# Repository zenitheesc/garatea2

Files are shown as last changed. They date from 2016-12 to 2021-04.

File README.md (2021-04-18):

<h1 align="center" style="color:white; background-color:black">Garatéa 2</h1>
<h4 align="center">Our aerospace probes are attached to balloons filled with helium, carrying astrobiological experiments to the stratosphere, which is crucial so we can have a better understanding about how organisms can survive in space.</h4>

<p align="center">
	<a href="http://zenith.eesc.usp.br/">
    
    </a>
    <a href="https://eesc.usp.br/">
    
    </a>
    <a href="https://github.com/zenitheesc/garatea2/blob/main/LICENSE">
    
    </a>
    <a href="https://github.com/zenitheesc/garatea2/issues">
    
    </a>
    <a href="https://github.com/zenitheesc/garatea2/commits/main">
    
    </a>
    <a href="https://github.com/zenitheesc/garatea2/graphs/contributors">
    
    </a>
    <a href="https://github.com/zenitheesc/garatea2/commits/main">
    
    </a>
    <a href="https://github.com/zenitheesc/garatea2/issues">
    
    </a>
    <a href="https://github.com/zenitheesc/garatea2/pulls">
    
    </a>
</p>

<p align="center">
    <a href="#what-are-aerospace-probes">What are aerospace probes?</a> •
    <a href="#project">Project</a> •
    <a href="#details">Details</a> 
</p>

## What are aerospace probes?

 Our aerospace probes are balloons filled with helium, carrying astrobiological experiments to the stratosphere, which is crucial so we can have a better understanding about how organisms can survive in space.

Although they are part of a greater scientific experiment, the probes themselves are also fascinating from the point of view of embedded systems development. Our probes are equiped with microcontrolers, radios, sensors and cameras; every mission we aim to improve our systems so we can make the next mission even more efficient.

And, to sustain all our experiments and systems, we build reliable and reusable structures, that let us go to space multiple times. 

## Project

After Garatéa-1, our primary goal was to increase the quality of our Space Probes. The Embedded System Architecture was based on an Atmega. In software, we decide to pure C without the use of the Arduino functions, but we also permit the use of C++ during development. We also use Arduino Watchdog Timer. 

In our previous Space Probe, the sensors reads were not constant, because we didn't have solar panels. Now that we do, energy-saving was no longer an issue for us. So, we were able to make many reads. That was also our first try to use GitHub for code versioning. 

The structure was made with Kapton, Aeronautic Depron, 3D printing and Glass Fiber. 

## Details
| Launch Date |Max Altitude|Experiments|
|--|--|--|
| 19/12/2016 | 25,5 km |Bacteria Resistance testing & Biomolecules degradation pattern analysis|

| | | |
|:---:|:---:|:---:|
| |  ||
|  |  | |

---

<p align="center">
    <a href="http://zenith.eesc.usp.br">
    
    </a> 
    <a href="https://www.facebook.com/zenitheesc">
    
    </a> 
    <a href="https://www.instagram.com/zenith_eesc/">
    
    </a>

</p>
<p align = "center">
<a href="zenith.eesc@gmail.com">zenith.eesc@gmail.com</a>
</p>

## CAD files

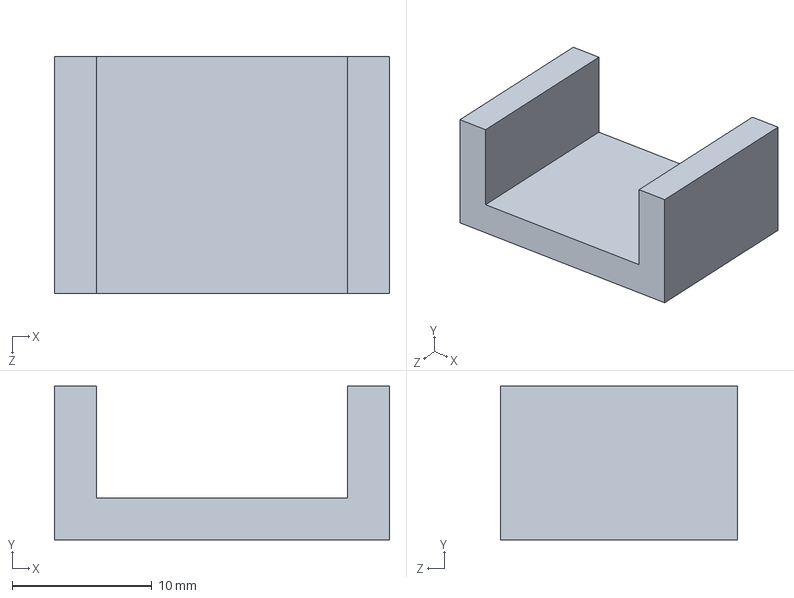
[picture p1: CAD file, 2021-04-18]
Structure/GPS Support.SLDPRT
24.0 x 11.0 x 17.0 mm

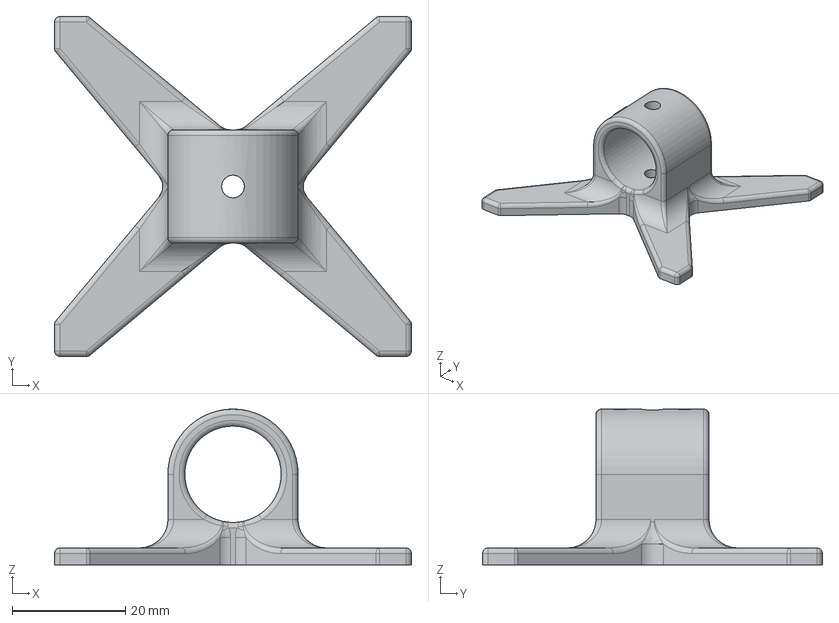
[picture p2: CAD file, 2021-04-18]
Structure/Solar Panel Support.stp
63.0 x 60.0 x 27.5 mm

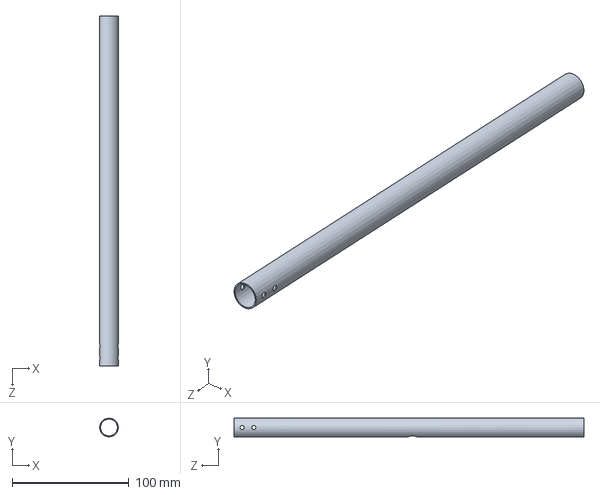
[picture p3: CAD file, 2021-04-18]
Structure/Tube.SLDPRT
16.0 x 16.0 x 300.0 mm

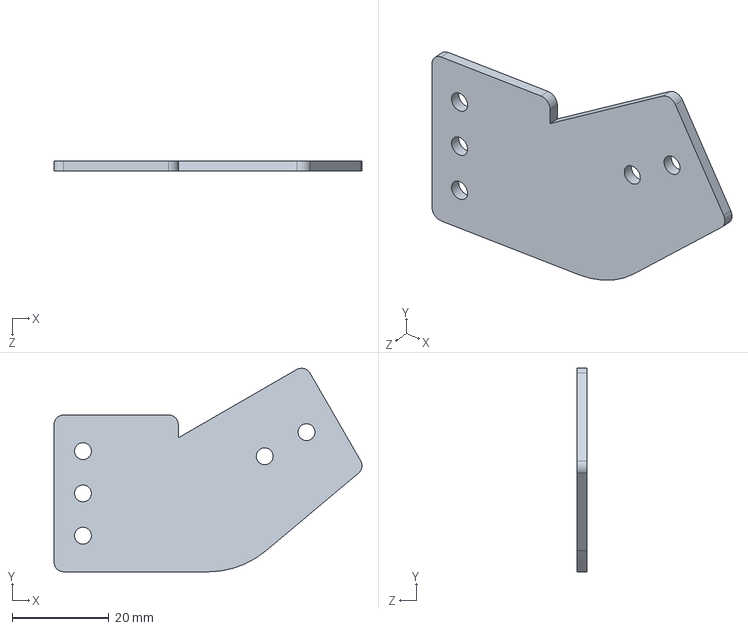
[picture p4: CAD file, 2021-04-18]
Structure/Elbow Board.SLDPRT
63.8 x 42.2 x 2.00 mm

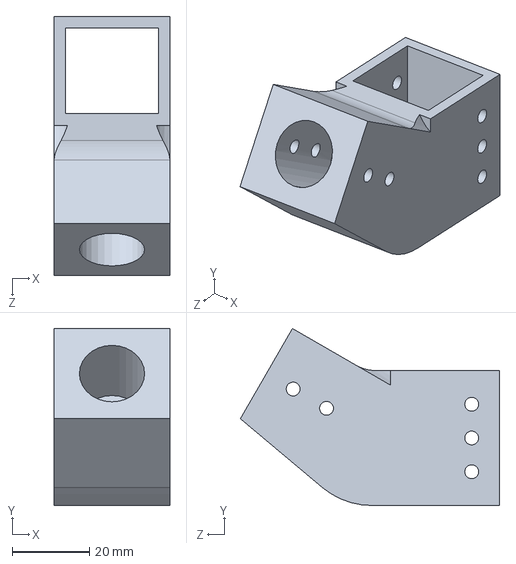
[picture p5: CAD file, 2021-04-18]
Structure/Final Elbow.SLDPRT
30.0 x 45.9 x 67.2 mm

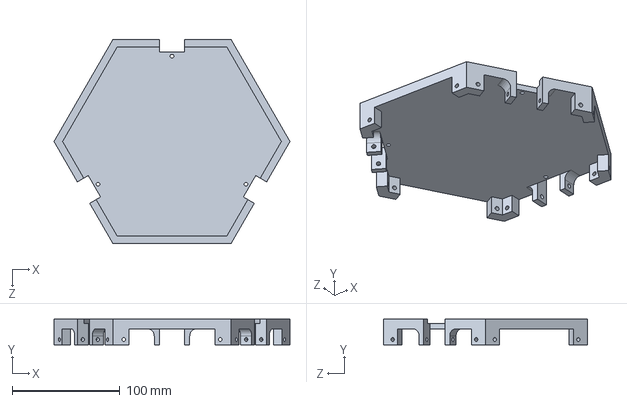
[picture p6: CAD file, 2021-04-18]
Structure/Lower Cover.SLDPRT
219.4 x 24.0 x 190.0 mm

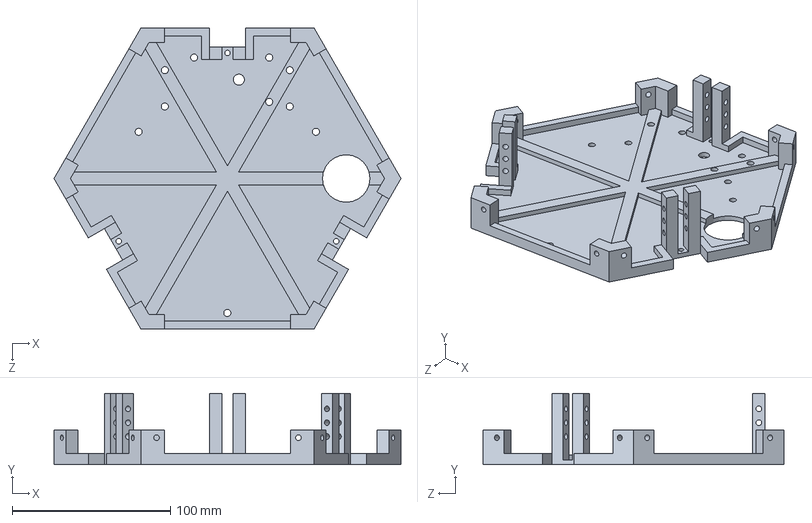
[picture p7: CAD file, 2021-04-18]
Structure/Higher Cover.SLDPRT
219.4 x 45.0 x 190.0 mm

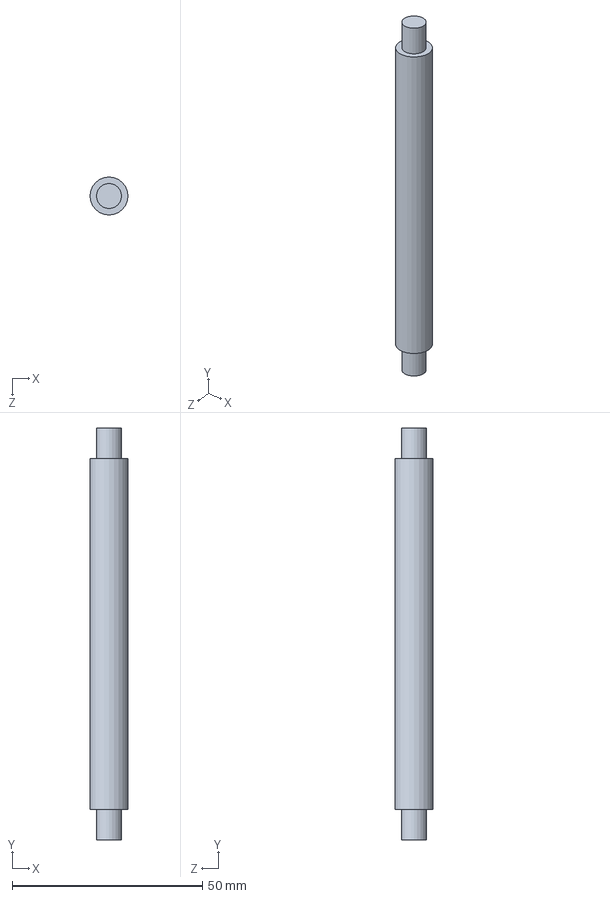
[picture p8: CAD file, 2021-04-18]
Structure/Geiger Counter.SLDPRT
10.0 x 108.4 x 10.0 mm

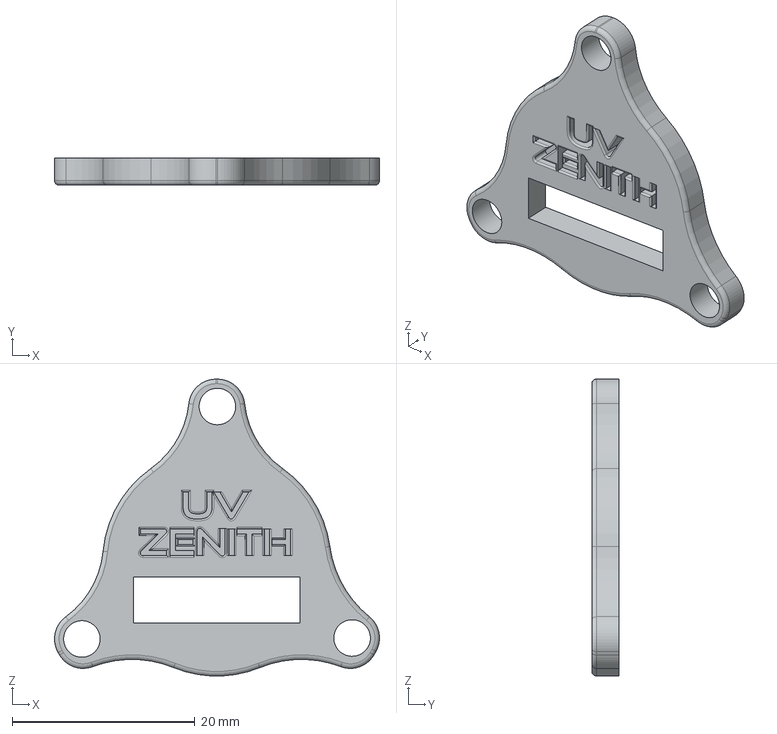
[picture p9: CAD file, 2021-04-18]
Structure/UV Cover.stp
35.6 x 3.00 x 32.5 mm

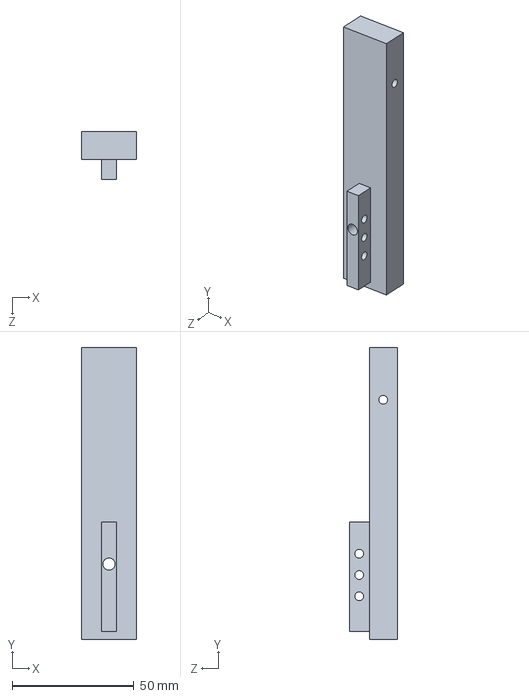
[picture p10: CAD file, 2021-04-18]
Structure/Collum.SLDPRT
22.5 x 120.0 x 19.8 mm

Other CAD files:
Structure/Solar Panel Support.SLDPRT

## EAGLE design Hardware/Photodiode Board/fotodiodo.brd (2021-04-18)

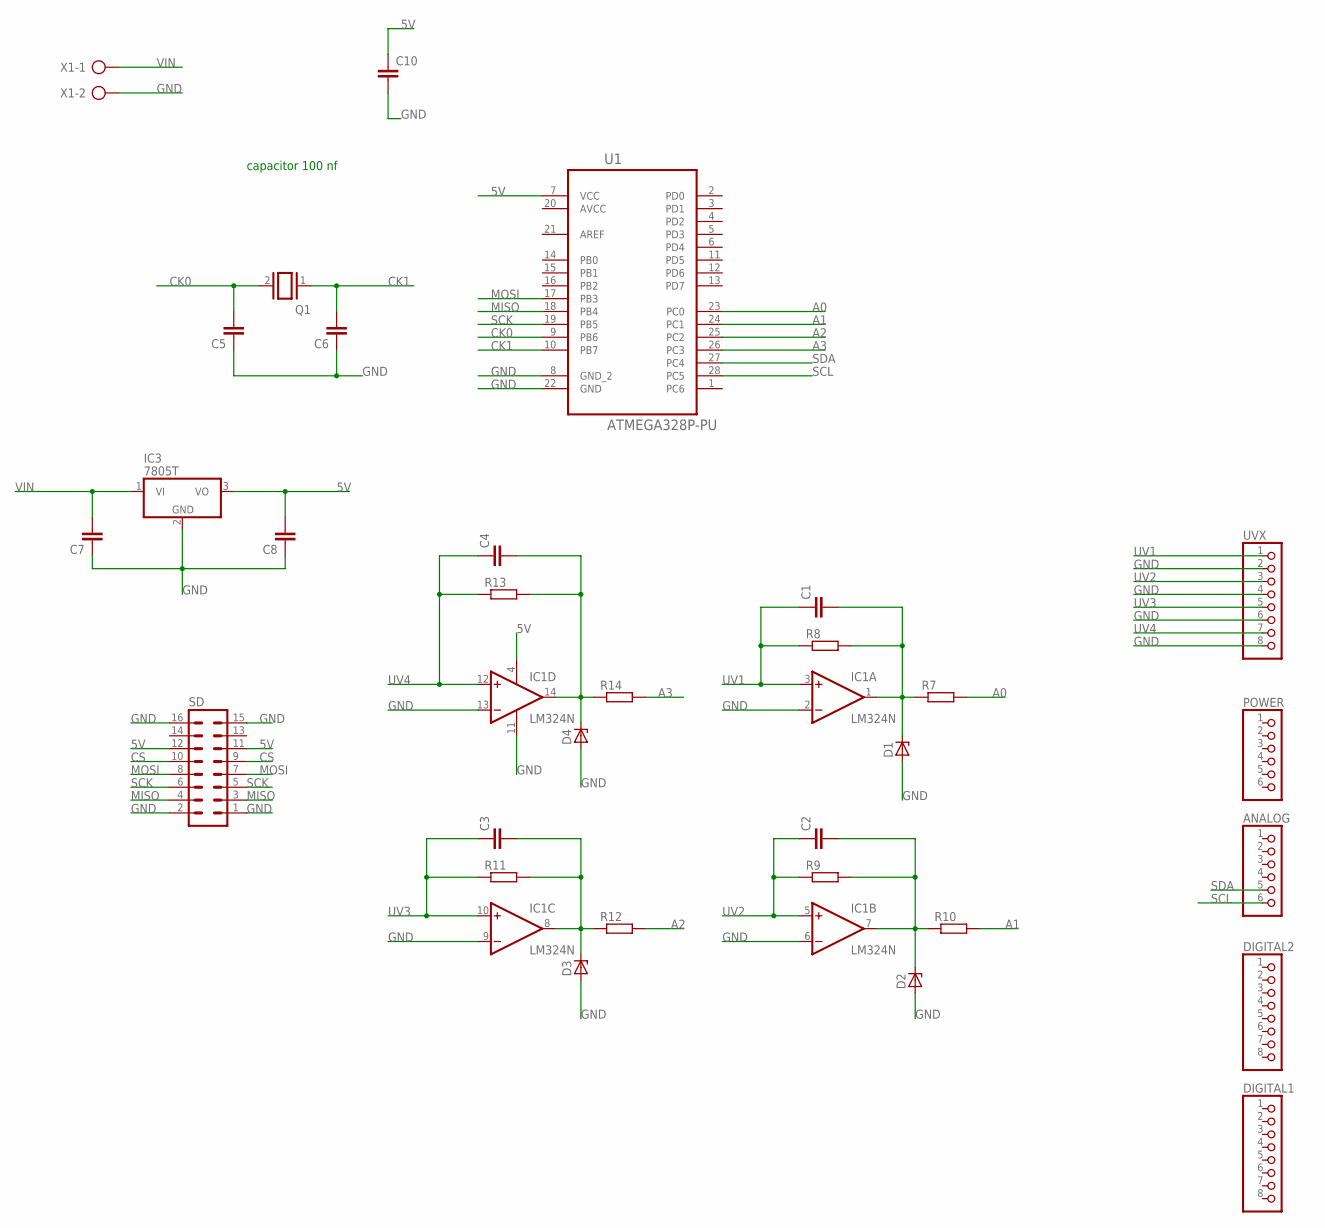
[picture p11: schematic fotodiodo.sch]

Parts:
ANALOG: PINHD-1X6; 1X06
C1, C2, C3, C4, C5, C6, C7, C8: C-EU025-025X050; C025-025X050
C10: C-EU050-055X075; C050-055X075
D1, D2, D3, D4: ZENER-DIODEC1702-15; C1702-15
DIGITAL1, DIGITAL2: PINHD-1X8; 1X08
IC1: LM324N; DIL14
IC3: 7805T; TO220H
POWER: PINHD-1X6; 1X06
Q1: XTAL/S; QS
R7, R8, R9, R10, R11, R12, R13, R14: R-EU_0207/10; 0207/10
SD: MA08-2
U1: ATMEGA328P-PU; DIP254P762X457-28
UVX: PINHD-1X8; 1X08
X1: AK500/2-H

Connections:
5V: C8.2, C10.1, IC1.4 (V+), IC3.3 (VO), SD.11, SD.12, U1.7 (VCC)
A0: R7.2, U1.23 (PC0)
A1: R10.2, U1.24 (PC1)
A2: R12.2, U1.25 (PC2)
A3: R14.2, U1.26 (PC3)
AVCC: U1.20 (AVCC)
CK0: C5.2, Q1.2, U1.9 (PB6)
CK1: C6.2, Q1.1, U1.10 (PB7)
CS: SD.9, SD.10
GND: C5.1, C6.1, C7.1, C8.1, C10.2, D1.A, D2.A, D3.A, D4.A, IC1.2 (-IN), IC1.6 (-IN), IC1.9 (-IN), IC1.11 (V-), IC1.13 (-IN), IC3.2 (GND), SD.1, SD.2, SD.15, SD.16, U1.8 (GND_2), U1.22 (GND), UVX.2, UVX.4, UVX.6, UVX.8, X1.2
MISO: SD.3, SD.4, U1.18 (PB4)
MOSI: SD.7, SD.8, U1.17 (PB3)
unnamed: C1.2, D1.C, IC1.1 (OUT), R7.1, R8.2
unnamed: C4.2, D4.C, IC1.14 (OUT), R13.2, R14.1
unnamed: C3.2, D3.C, IC1.8 (OUT), R11.2, R12.1
unnamed: C2.2, D2.C, IC1.7 (OUT), R9.2, R10.1
SCK: SD.5, SD.6, U1.19 (PB5)
SCL: ANALOG.6, U1.28 (PC5)
SDA: ANALOG.5, U1.27 (PC4)
UV1: C1.1, IC1.3 (+IN), R8.1, UVX.1
UV2: C2.1, IC1.5 (+IN), R9.1, UVX.3
UV3: C3.1, IC1.10 (+IN), R11.1, UVX.5
UV4: C4.1, IC1.12 (+IN), R13.1, UVX.7
VIN: C7.2, IC3.1 (VI), X1.1

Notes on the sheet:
capacitor 100 nf

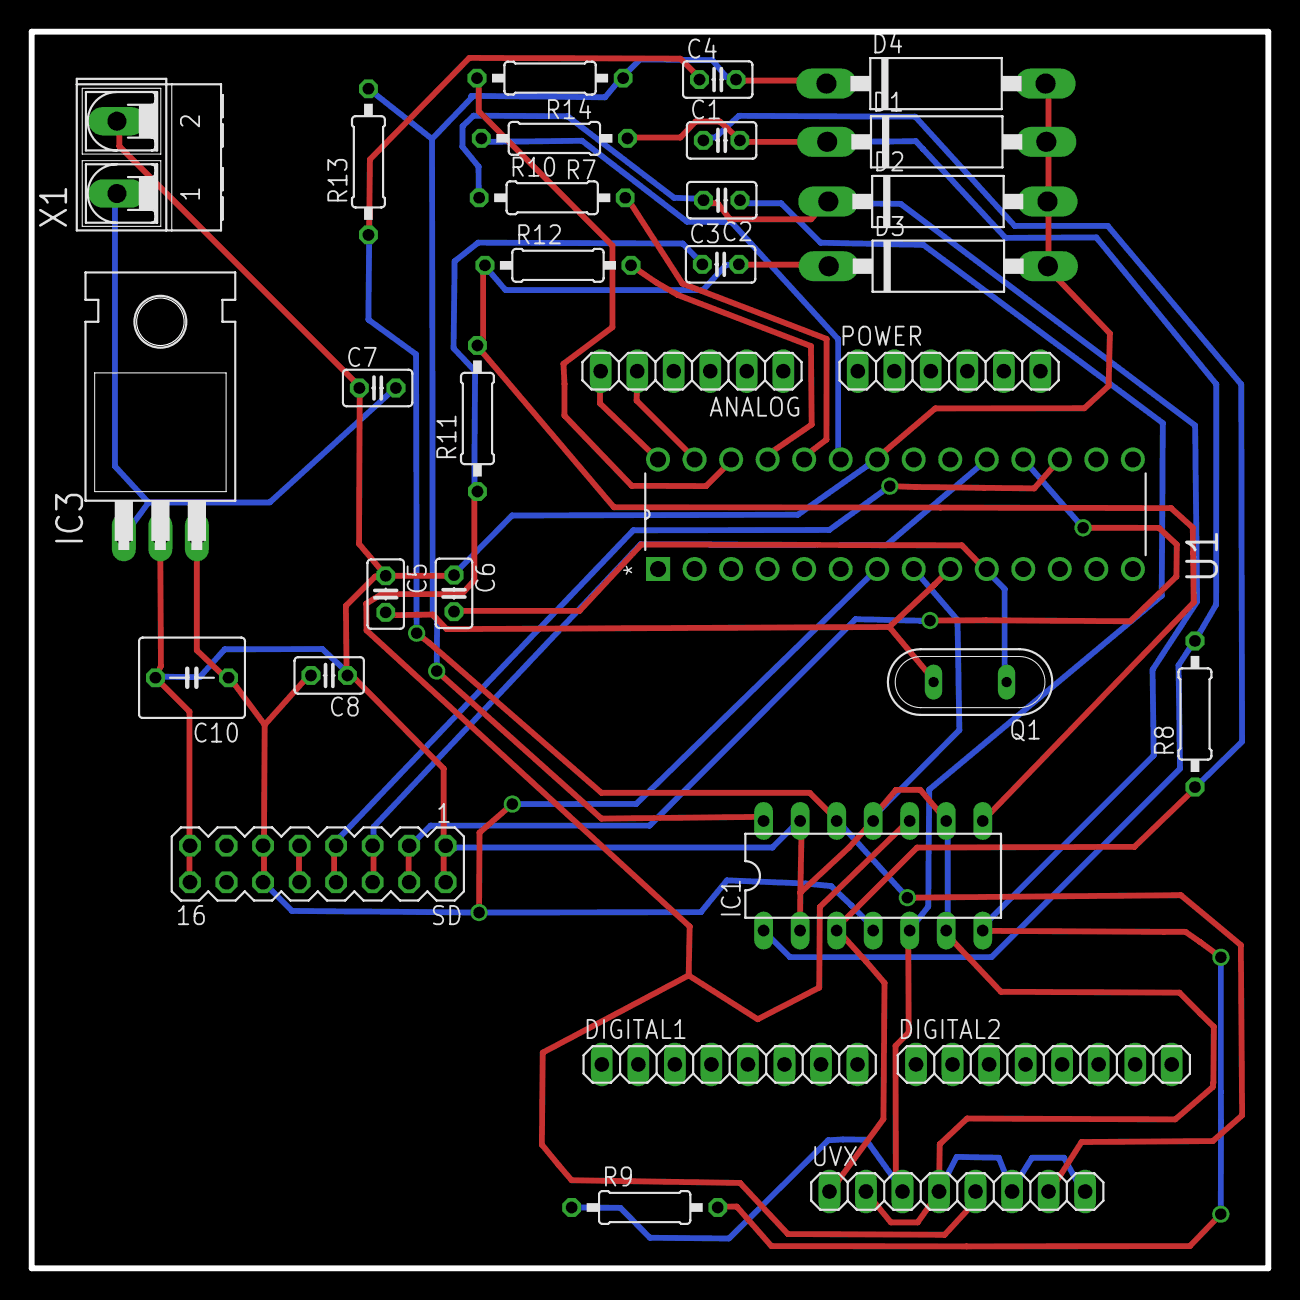
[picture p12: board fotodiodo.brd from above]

Board: 2 copper layers, 86.0 x 86.0 mm, 32 parts (0 on the bottom side), 23 nets.

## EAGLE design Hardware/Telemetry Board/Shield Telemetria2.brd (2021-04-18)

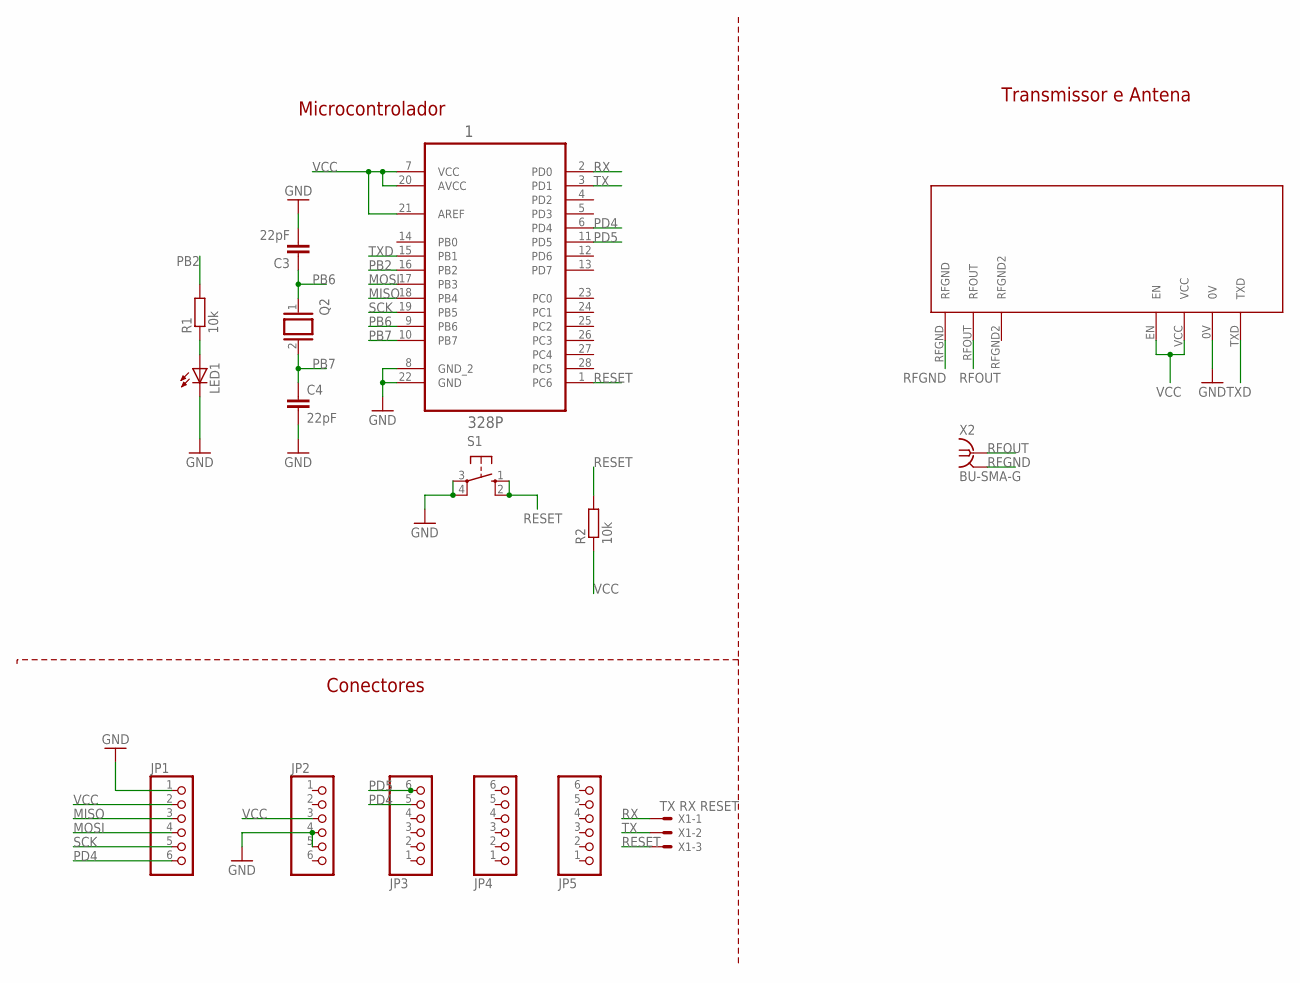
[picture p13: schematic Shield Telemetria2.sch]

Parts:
1: 328P; DIP254P762X457-28
C3, C4: 22pF; C5B4.5
JP1, JP2, JP3, JP4, JP5: PINHD-1X6; 1X06
LED1: LED3MM
Q2: XTAL/S; QS
R1, R2: 10k; 0207/10
S1: 10-XX; B3F-10XX
U$1: NTX2
X1: TX RX RESET; 22-23-2031
X2: BU-SMA-G

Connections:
GND: 1.8 (GND_2), 1.22 (GND), C3.2, C4.2, JP1.1, JP2.4, JP2.5, LED1.K (C), S1.3, S1.4 (P1), U$1.0V
MISO: 1.18 (PB4), JP1.3
MOSI: 1.17 (PB3), JP1.4
unnamed: LED1.A, R1.1
PB2: 1.16 (PB2), R1.2
PB6: 1.9 (PB6), C3.1, Q2.1
PB7: 1.10 (PB7), C4.1, Q2.2
PD4: 1.6 (PD4), JP1.6, JP3.5
PD5: 1.11 (PD5), JP3.6
RESET: 1.1 (PC6), R2.2, S1.1 (S), S1.2 (S1), X1.3
RFGND: U$1.RFGND, X2.2, X2.3 (2), X2.4 (2), X2.5 (2)
RFOUT: U$1.RFOUT, X2.1
RX: 1.2 (PD0), X1.1
SCK: 1.19 (PB5), JP1.5
TX: 1.3 (PD1), X1.2
TXD: 1.15 (PB1), U$1.TXD
VCC: 1.7 (VCC), 1.20 (AVCC), 1.21 (AREF), JP1.2, JP2.3, R2.1, U$1.EN, U$1.VCC

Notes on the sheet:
Conectores
Microcontrolador
Transmissor e Antena

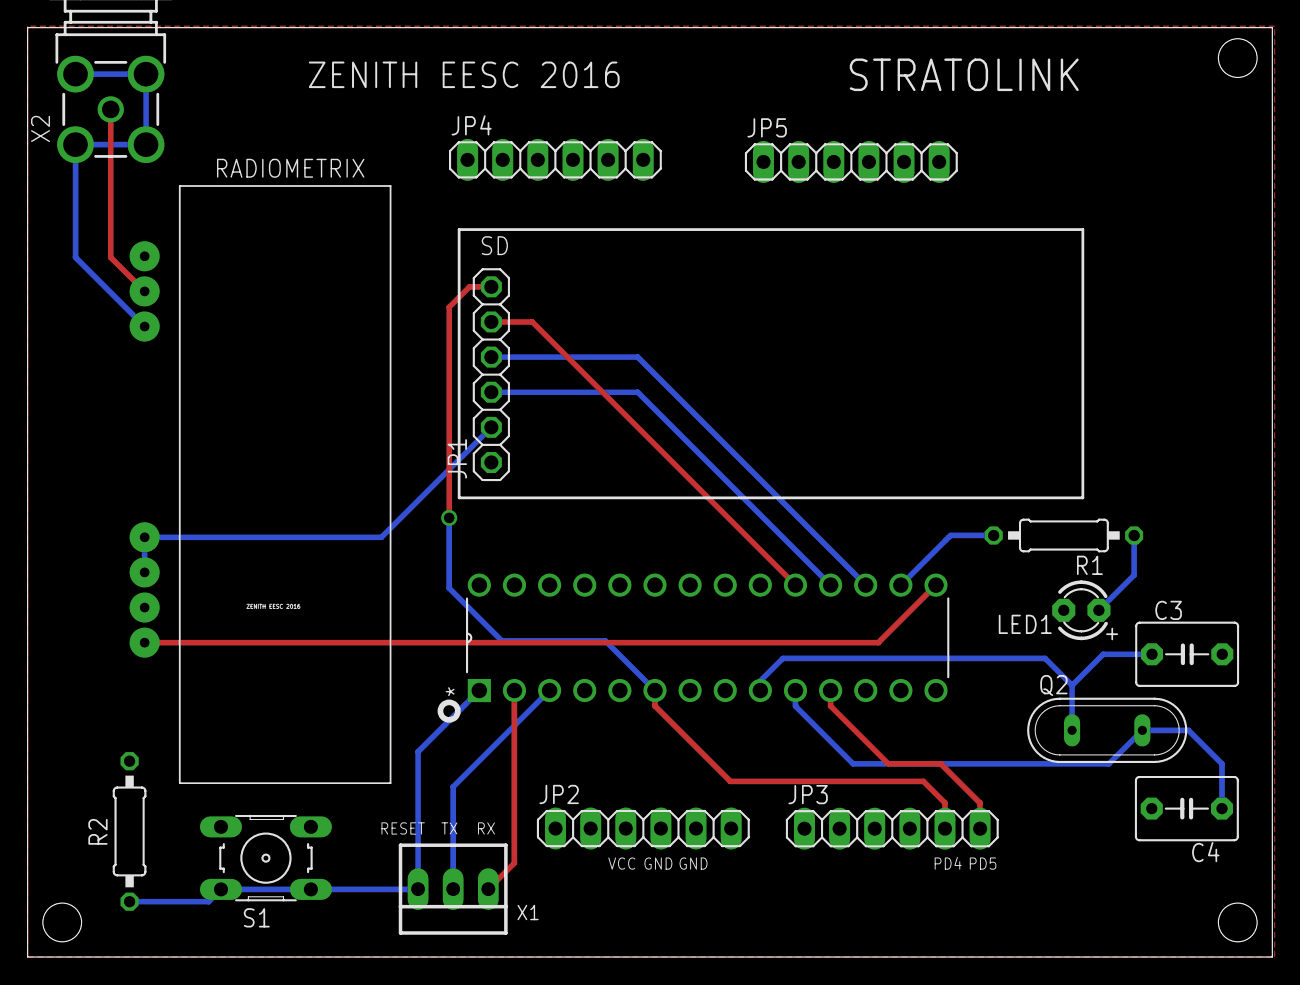
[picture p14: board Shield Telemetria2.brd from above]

Board: 2 copper layers, 90.0 x 67.2 mm, 16 parts (0 on the bottom side), 17 nets.

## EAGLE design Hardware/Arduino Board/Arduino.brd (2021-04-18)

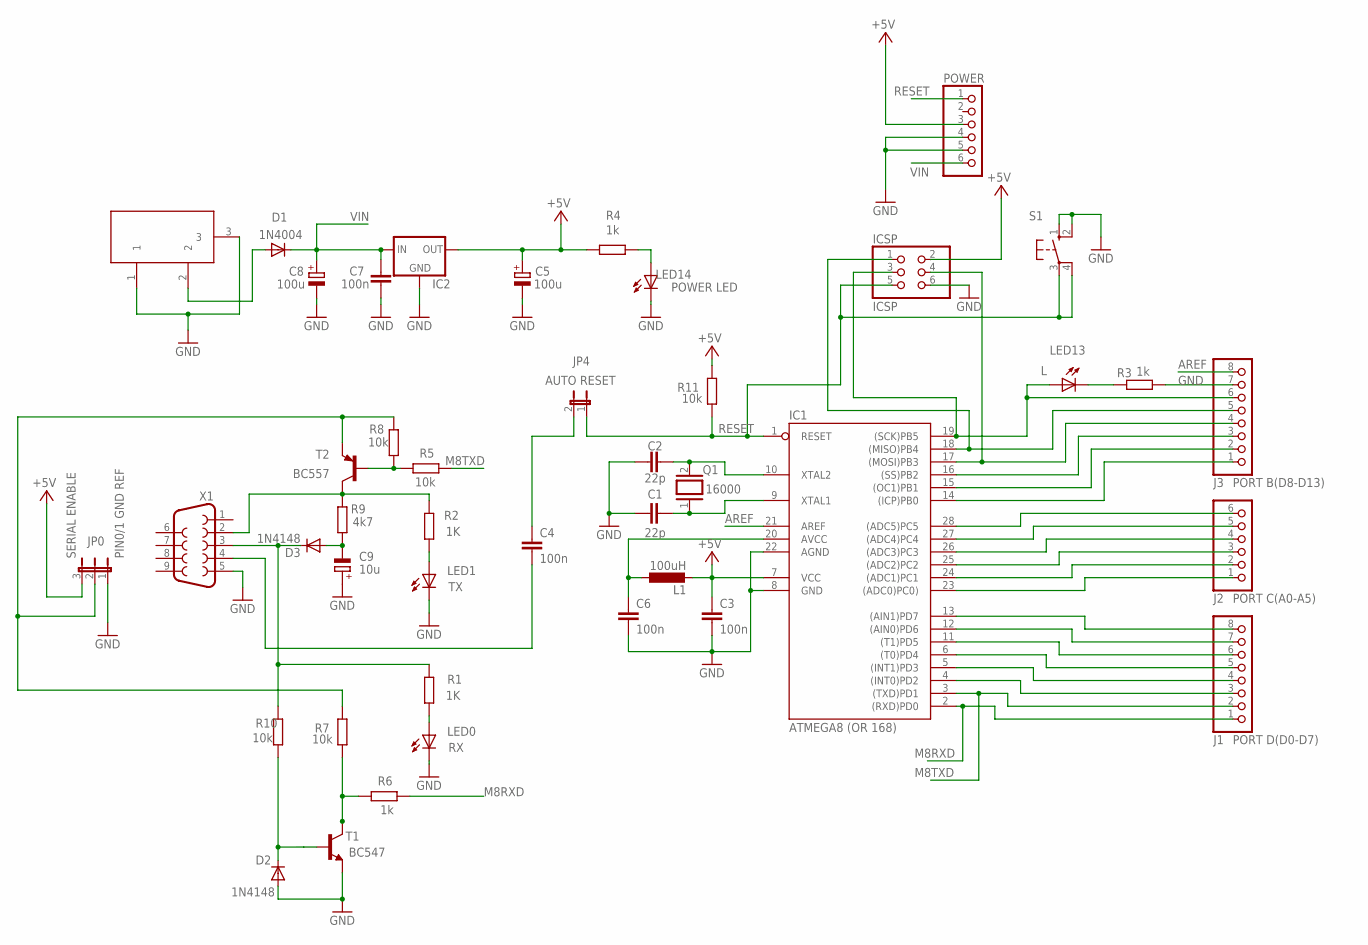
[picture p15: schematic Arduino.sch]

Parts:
C1, C2: 22p; C050-025X075
C3, C4, C6, C7: 100n; C050-025X075
C5, C8: 100u; E3,5-8
C9: 10u; E5-6
D1: 1N4004; DO41-10
D2, D3: 1N4148; DO35-10
DC1: DC21MMX; DC-21MM
IC1: ATMEGA8 (OR 168); DIL28-3
IC2: 78XXL
ICSP: ICSP; 2X03
J1: PORT D(D0-D7); 1X08
J2: PORT C(A0-A5); 1X06
J3: PORT B(D8-D13); 1X08
JP0: JP2W
JP4: AUTO RESET; JP1W
L1: 100uH; 0207/10
LED0: RX; LED3MM
LED1: TX; LED3MM
LED13: L; LED3MM
LED14: POWER LED; LED3MM
POWER: PINHD-1X6; 1X06
Q1: 16000; Q
R1, R2: 1K; 0207/10
R3, R4, R6: 1k; 0207/10
R5, R7, R8, R10, R11: 10k; 0207/10
R9: 4k7; 0207/10
S1: 10-XX; B3F-10XX
T1: BC547; TO92
T2: BC557; TO92-EBC
X1: F09H

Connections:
+5V: C3.1, C5.+, IC1.7 (VCC), IC2.OUT, ICSP.2, JP0.3, L1.2, POWER.3, R4.2, R11.2
AREF: IC1.21 (AREF), J3.8
GND: C1.1, C2.1, C3.2, C5.-, C6.2, C7.1, C8.-, C9.+, D2.A, DC1.1, DC1.3, IC1.8 (GND), IC1.22 (AGND), IC2.GND, ICSP.6, J3.7, JP0.1, LED0.K (C), LED1.K (C), LED14.K (C), POWER.4, POWER.5, R3.1, S1.1 (S), S1.2 (S1), T1.1 (E), X1.5
M8RXD: IC1.2 ((RXD)PD0), J1.1, R6.1
M8TXD: IC1.3 ((TXD)PD1), J1.2, R5.1
unnamed: IC1.18 ((MISO)PB4), ICSP.1, J3.5
unnamed: C9.-, D3.A, R9.1
unnamed: LED14.A, R4.1
unnamed: IC1.17 ((MOSI)PB3), ICSP.4, J3.4
unnamed: IC1.14 ((ICP)PB0), J3.1
unnamed: C1.2, IC1.9 (XTAL1), Q1.1
unnamed: C2.2, IC1.10 (XTAL2), Q1.2
unnamed: D1.A, DC1.2
unnamed: IC1.4 ((INT0)PD2), J1.3
unnamed: IC1.5 ((INT1)PD3), J1.4
unnamed: IC1.6 ((T0)PD4), J1.5
unnamed: IC1.11 ((T1)PD5), J1.6
unnamed: IC1.12 ((AIN0)PD6), J1.7
unnamed: IC1.13 ((AIN1)PD7), J1.8
unnamed: IC1.23 ((ADC0)PC0)), J2.1
unnamed: IC1.24 ((ADC1)PC1), J2.2
unnamed: IC1.25 ((ADC2)PC2), J2.3
unnamed: IC1.26 ((ADC3)PC3), J2.4
unnamed: IC1.27 ((ADC4)PC4), J2.5
unnamed: IC1.28 ((ADC5)PC5), J2.6
unnamed: IC1.15 ((OC1)PB1), J3.2
unnamed: IC1.16 ((SS)PB2), J3.3
unnamed: D3.C, R1.2, R10.2, X1.3
unnamed: R6.2, R7.1, T1.3 (C)
unnamed: R5.2, R8.2, T2.B
unnamed: D2.C, R10.1, T1.2 (B)
unnamed: LED13.K (C), R3.2
unnamed: LED1.A, R2.1
unnamed: LED0.A, R1.1
unnamed: C4.1, JP4.2
unnamed: C4.2, X1.4
unnamed: R2.2, R9.2, T2.C, X1.2
unnamed: C6.1, IC1.20 (AVCC), L1.1
RESET: IC1.1 (RESET), ICSP.5, JP4.1, POWER.1, R11.1, S1.3, S1.4 (P1)
SCK: IC1.19 ((SCK)PB5), ICSP.3, J3.6, LED13.A
SERIAL_VCC: JP0.2, R7.2, R8.1, T2.E
VIN: C7.2, C8.+, D1.C, IC2.IN, POWER.6

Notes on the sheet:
PIN0/1 GND REF
SERIAL ENABLE

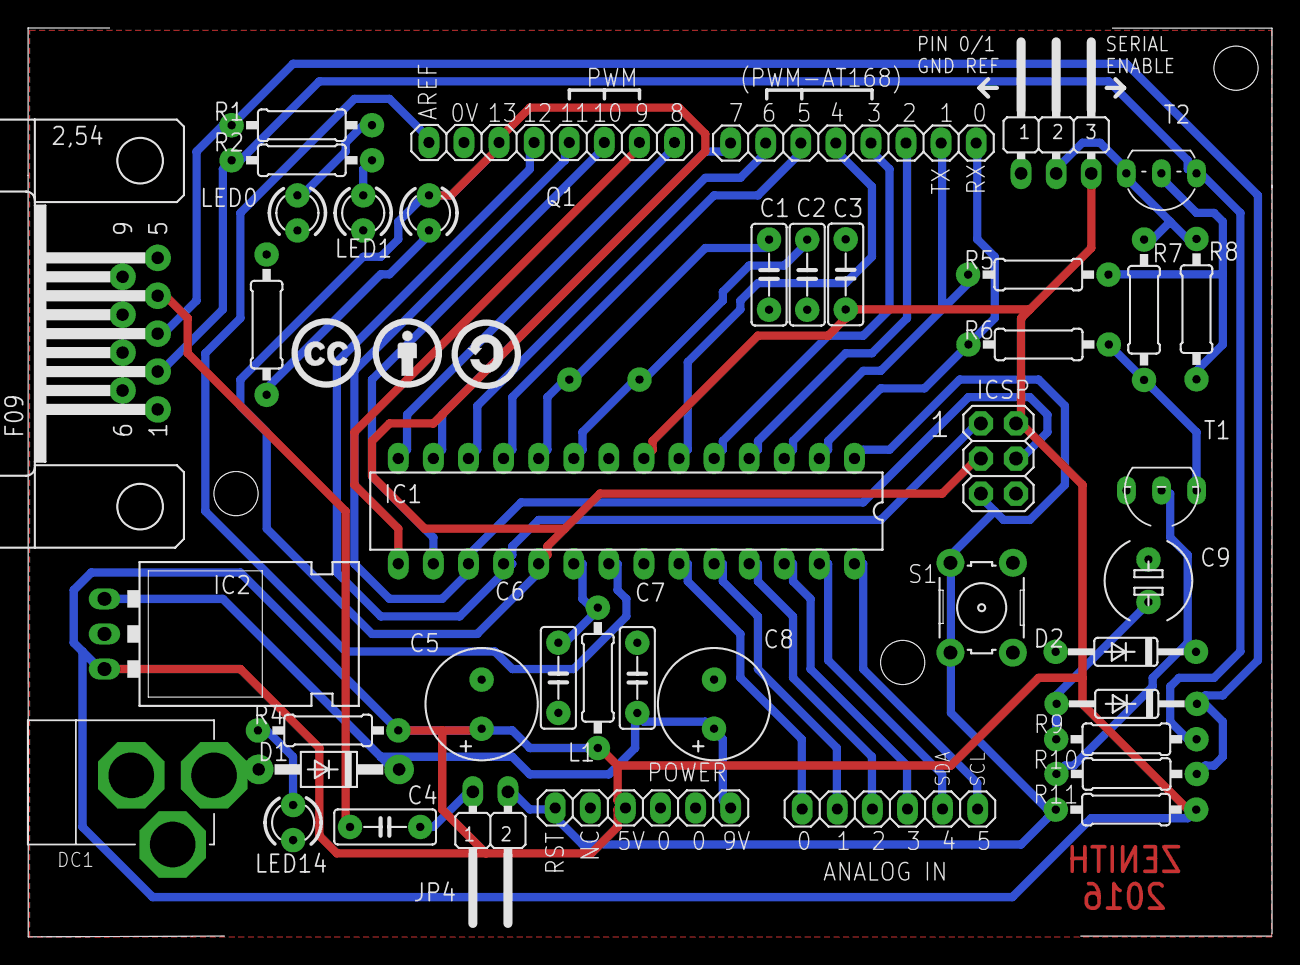
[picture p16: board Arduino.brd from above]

Board: 2 copper layers, 90.1 x 65.8 mm, 46 parts (1 on the bottom side), 42 nets.

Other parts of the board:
U$1: CC
U$2: BY
U$3: SA

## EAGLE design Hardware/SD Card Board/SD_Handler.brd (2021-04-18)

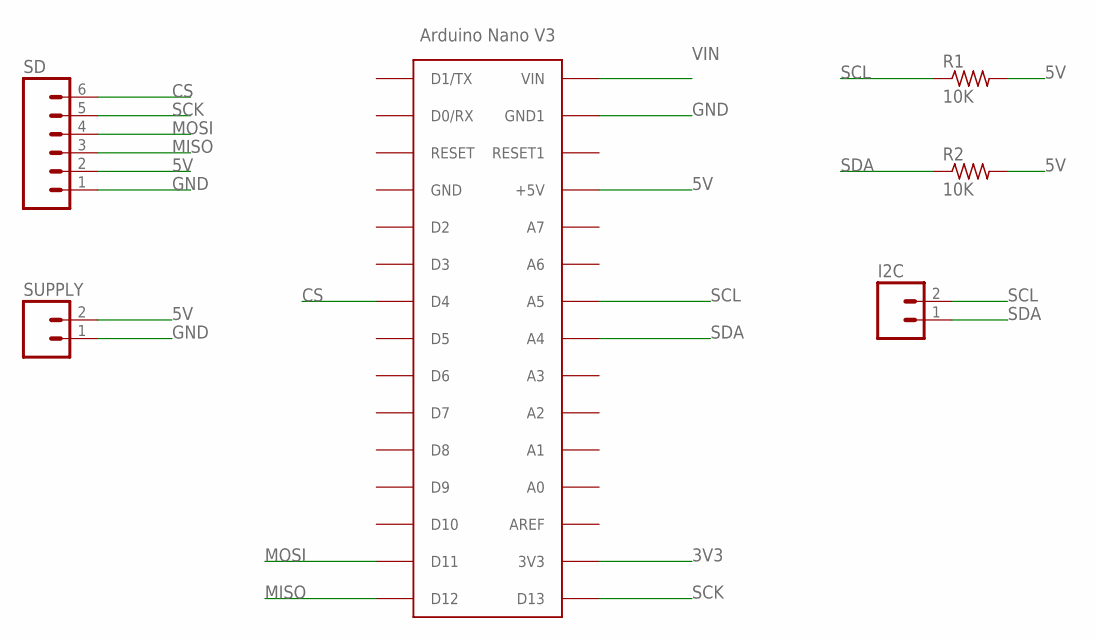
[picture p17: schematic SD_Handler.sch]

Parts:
I2C: M02; 02P
R1, R2: 10K; 0207/10
SD: M06LONGPADS; 1X06_LONGPADS
SUPPLY: M02; 02P
U$1: ARDUINONANO; PDIP-32

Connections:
3V3: U$1.3V3
5V: R1.2, R2.2, SD.2, SUPPLY.2, U$1.+5V
CS: SD.6, U$1.D4
GND: SD.1, SUPPLY.1, U$1.GND1
MISO: SD.3, U$1.D12
MOSI: SD.4, U$1.D11
SCK: SD.5, U$1.D13
SCL: I2C.2, R1.1, U$1.A2 (A5)
SDA: I2C.1, R2.1, U$1.A3 (A4)
VIN: U$1.VIN

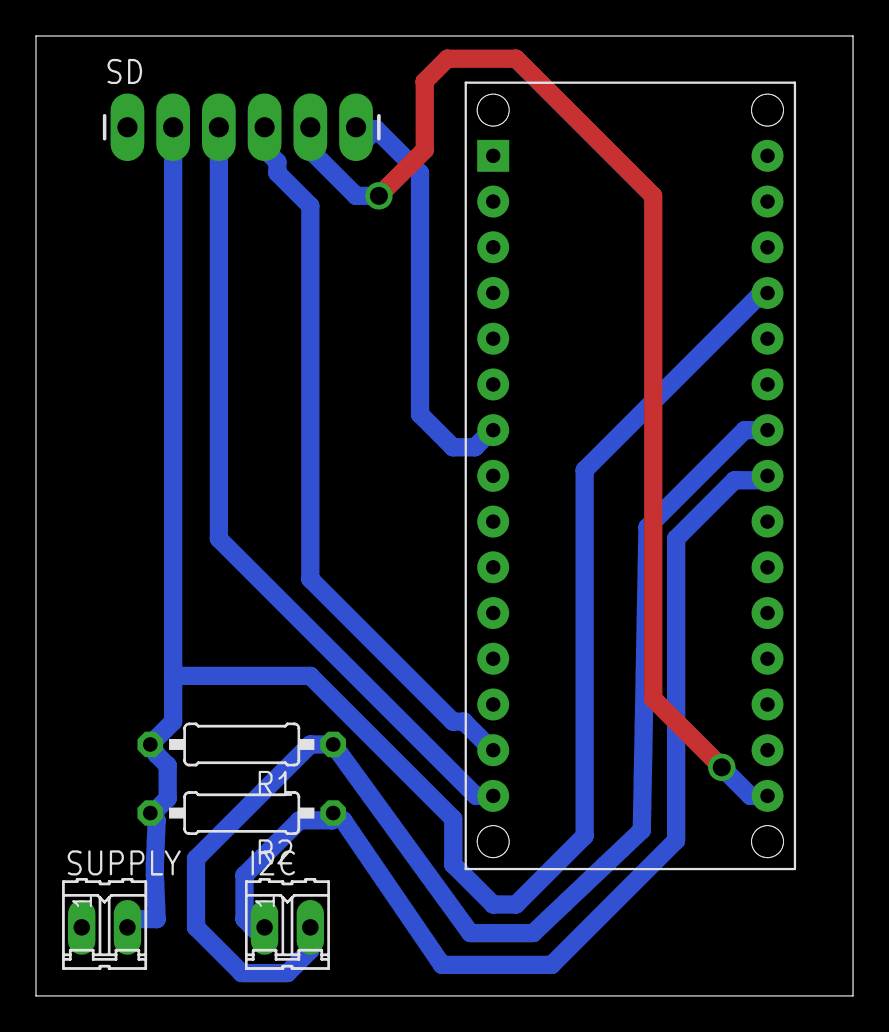
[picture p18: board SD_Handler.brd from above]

Board: 2 copper layers, 45.4 x 53.3 mm, 6 parts (0 on the bottom side), 8 nets.

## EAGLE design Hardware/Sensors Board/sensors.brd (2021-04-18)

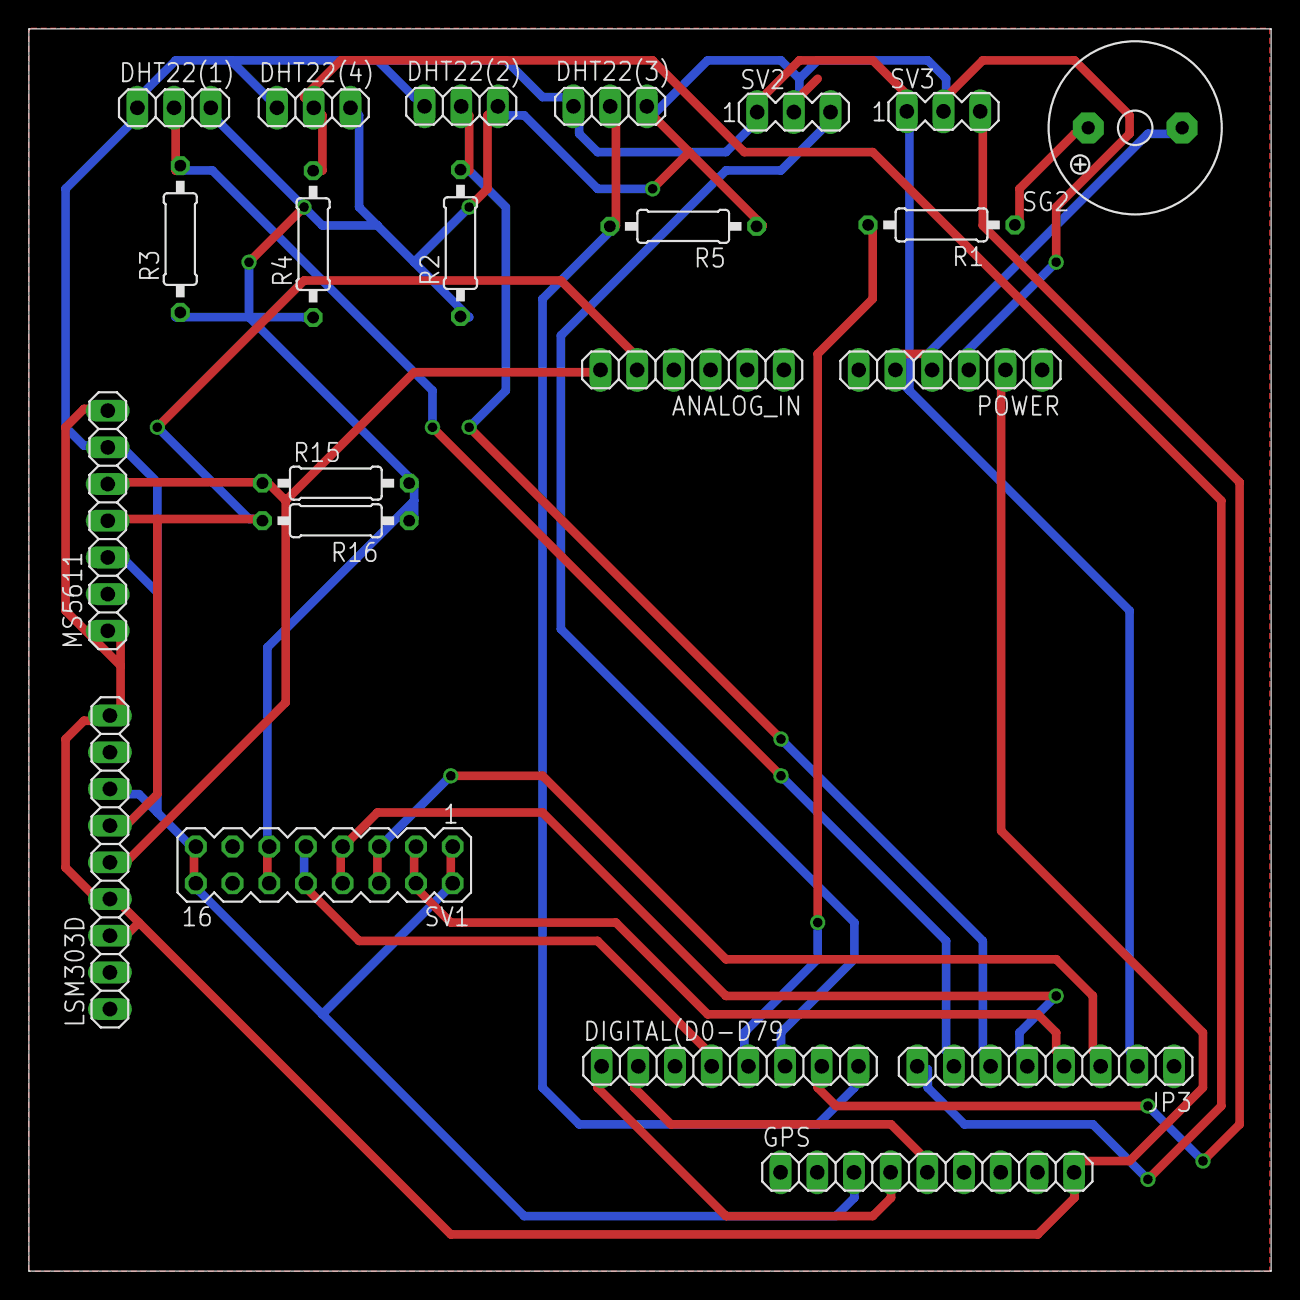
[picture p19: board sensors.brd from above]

Board: 2 copper layers, 86.0 x 86.0 mm, 22 parts (0 on the bottom side), 19 nets.

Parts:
ANALOG_IN: 1X06
DHT22(1), DHT22(2), DHT22(3), DHT22(4): 1X03
DIGITAL(D0-D79: 1X08
GPS: 1X09
JP3: 1X08
LSM303D: 1X09
MS5611: 1X07
POWER: 1X06
R1, R2, R3, R4, R5, R15, R16: 0207/10
SG2: F/QMBIII
SV1: MA08-2
SV2, SV3: MA03-1

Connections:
3.3V: GPS.9, LSM303D.3, LSM303D.4, LSM303D.9, MS5611.1, MS5611.7, POWER.2
5: DIGITAL(D0-D79.6, SV2.3
5V: DHT22(1).3, DHT22(2).3, DHT22(3).3, DHT22(4).3, POWER.3, R2.1, R3.1, R4.1, R5.1, R15.2, R16.1, SV1.11, SV1.12, SV2.2, SV3.2
6: DIGITAL(D0-D79.7, SV3.3
7: DHT22(3).2, DIGITAL(D0-D79.8, R5.2
8: DHT22(4).2, JP3.8, R4.2
9: DHT22(1).2, JP3.7, R3.2
10: DHT22(2).2, JP3.6, R2.2
BUZZER: DIGITAL(D0-D79.5, R1.2
CS: DIGITAL(D0-D79.4, SV1.9, SV1.10
GND: DHT22(1).1, DHT22(2).1, DHT22(3).1, DHT22(4).1, GPS.3, JP3.2, LSM303D.7, MS5611.3, MS5611.6, POWER.4, POWER.5, SG2.-, SV1.1, SV1.2, SV1.15, SV1.16, SV2.1, SV3.1
MISO: JP3.4, SV1.3, SV1.4
MOSI: JP3.5, SV1.7, SV1.8
unnamed: R1.1, SG2.+
RX: DIGITAL(D0-D79.1, GPS.4
SCK: JP3.3, SV1.5, SV1.6
SCL: ANALOG_IN.6, LSM303D.5, MS5611.5, R15.1
SDA: ANALOG_IN.5, LSM303D.6, MS5611.4, R16.2
TX: DIGITAL(D0-D79.2, GPS.5

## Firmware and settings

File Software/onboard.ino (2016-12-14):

//#include <avr/wdt.h> // Biblioteca utilizada pelo watchdog timer.
#include "StateMach.h"

StateMach estados;

void setup(){
    Serial.begin(9600);     
    //wdt_enable(WDTO_4S); // Computador ira reiniciar se o timer nao for resetado em 4s
    pinMode(4, OUTPUT);
    Serial.println(F("oi"));
}

void loop(){
    digitalWrite(4, LOW);
    Serial.println(F("loop"));
    //wdt_reset(); // Funcao que reseta o timer
    estados.Main_State();
    delay(2000);
}

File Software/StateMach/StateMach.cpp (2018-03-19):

#include "StateMach.h"

void StateMach::Main_State(){

    Serial.println(F("I'm in Main state.")); 

    // Start all sensors
    START_ALL();

    // Counter to send to telemetry
    contador = 0;

    // Mode execution loop
   while(true) {
        if(this->_climbingMode) ClimbingMode();
       /* if(this->_exposureMode) ExposureMode();
        if(this->_fallingMode) FallingMode();
        if(this->_rescueMode) RescueMode();*/
    }

}

void StateMach::ClimbingMode(){

    Serial.println("I'm in ClimbingMode");    
	//_buzzer.beep(); // Pisca Buzzer 1 vez pra sabermos que estamos no modo 1 
    Serial.println(contador);
    READ_ALL();
    Serial.println(F("All sensors read."));
    Serial.println(contador);
    SERIAL_PRINT_ALL();
    Serial.println(F("All sensors printed."));
    Serial.println(contador);
    SAVE_ALL();
    Serial.println(F("All data sent to SD card."));
    Serial.println(contador);

    // Telemetry condition
    if( contador > 9 ){
        TELEMETRIA();
        Serial.println(F("Enviou a string para a telemetria por i2c."));
        contador = 0;        
    } else {
        contador++;
        Serial.println(F("Sem tempo para telemetria."));
    }
    Serial.println(contador);

    // State machine check (to exposure mode)
    if (this->_gps1.altitude.meters() > ExposureModeAltitude || this->_gps2.altitude.meters() > ExposureModeAltitude/* BMP180 TBM */) {
        // Opens exp window
        this->_myServo.OpenWindow();

        this->_climbingMode = false;        
        this->_exposureMode = true;        
    }
}

void StateMach::ExposureMode(){

    // Exposure mode beep
    _buzzer.beeper(2);

    // Needs to check if sensors are available
    READ_ALL();
    SERIAL_PRINT_ALL();
    SAVE_ALL();
    TELEMETRIA();

    // Update angular coef data
    IsF.guardar_medidaGPS(_gps1.altitude.meters());
    IsF.guardar_medidaGPS(_gps2.altitude.meters());

    ND.addData(_gps1.altitude.meters());
    ND.addData(_gps2.altitude.meters());

    // Check if probe is falling
    if (this->_gps1.altitude.meters() > CloseWindowAltitude || this->_gps2.altitude.meters() > CloseWindowAltitude/* BMP180 TBM */) {
        if( IsF.isFallingBAR() || IsF.isFallingGPS() || ND.isFallingND() ) { 
            // Close exp window
            this->_myServo.CloseWindow();

            this->_exposureMode = false;
            this->_fallingMode = true;            
        }

        /* We no longer use an acelerometer (_hlsm303)
        if(this->_gps.altitude.meters() > 28000.0){
            if(_hlsm303.getMod() < 2.0){
                this->_myServo.CloseWindow();
                this->_exposureMode = false;
                this->_fallingMode = true;                
            }
        }*/
    }

    if(millis() == MaxTimeCloseWindow){
        this->_myServo.CloseWindow();
    }
}

void StateMach::FallingMode(){

    READ_ALL();
    SERIAL_PRINT_ALL();
    SAVE_ALL();
    TELEMETRIA();

    if (_gps1.altitude.meters() < RescueModeAltitude || _gps2.altitude.meters() < RescueModeAltitude) {
        this->_fallingMode = false;
        this->_rescueMode = true;
    }
}

void StateMach::RescueMode(){
    this->_buzzer.beeper(5);
    delay(10000);
}

void StateMach::START_ALL(){
    Serial.println("Inicializando sesores.");
    
    _ss.begin(GPSBaud);
    Serial.println(F("gps _ss ok"));

    _ubk.begin(GPSBaud);
    Serial.println(F("gps _ubk ok"));
    /*_gps.begin(9600);
    Serial.println(F("gps ok"));*/

    _myServo.setup(5);
    Serial.println(F("servo ok"));

    _dht.begin();
    Serial.println(F("dht ok"));

    _climbingMode = true;
    Wire.begin();

    Serial.println("Sensores incializados.");
}

void StateMach::READ_ALL(){

    _dht.readDHT();
    Serial.println(F("ok"));
    delay(5);
    
    /*_gps.read_GPS();
    Serial.println(F("ok"));
    delay(5);*/

    // Needs 2 gps

    // Needs EEPROM
    
    // Needs BMP180
}


void StateMach::SERIAL_PRINT_ALL(){
    //DHT
    Serial.println(_dht.getTemp()); 
    Serial.println(_dht.getHumd());
    Serial.println(_dht.getHIdx());


    //GPS
   /* Serial.println(_gps.get_fix());
    Serial.println(_gps.get_latitude());
    Serial.println(_gps.get_longitude());
    Serial.println(_gps.get_speed());
    Serial.println(_gps.altitude.meters());*/
    
    
}

void StateMach::SAVE_ALL() {
    strcat(SD1, "");
    strcat(SDaux, "");
    

    /*//GPS
    TC.number_to_string(SDaux, _gps.get_latitude());
    TC.computeData(SD1, SDaux); //10
    strcpy(SDaux, "");
    TC.number_to_string(SDaux, _gps.get_longitude());
    TC.computeData(SD1, SDaux); //10
    strcpy(SDaux, "");
    TC.number_to_string(SDaux, _gps.get_speed());
    TC.computeData(SD1, SDaux); //5
    strcpy(SDaux, "");
    TC.number_to_string(SDaux, _gps.altitude.meters());
    TC.computeData(SD1, SDaux); //7
    strcpy(SDaux, "");

    Wire.beginTransmission(15);
    Wire.write(SD1);
    Wire.endTransmission();
    strcpy(SD1, "");
    delay(1000);*/


    //DHT
    TC.number_to_string(SDaux, _dht.getTemp());
    TC.computeData(SD1, SDaux); //4
    strcpy(SDaux, "");
    TC.number_to_string(SDaux, _dht.getHumd());
    TC.computeData(SD1, SDaux); //4
    strcpy(SDaux, "");
    TC.number_to_string(SDaux, _dht.getHIdx());
    TC.computeData(SD1, SDaux); //2
    strcpy(SDaux, "");


    Wire.beginTransmission(15);
    Wire.write(SD1);
    Wire.endTransmission();
    Serial.println(SD1);
    strcpy(SD1, ""); 
    delay(500);

}

void StateMach::TELEMETRIA() {
   /* TC.saveData(_gps.get_latitude());
    TC.saveData(_gps.get_longitude());
    TC.saveData(_gps.altitude.meters());
    TC.saveData(_gps.get_speed());*/

    /*TC.saveData(_gps1.isValid());
    TC.saveData(_gps2.isValid());*/

    Serial.println(TC.getStringTel());

    TC.transmission(TC.getStringTel());
    
    TC.cleanStringTel();

    /*TC.saveData(_uvx.get_UVA());
    TC.saveData(_uvx.get_UVC());    
    TC.saveData(_uvx.get_UVB());
    

    TC.transmission(TC.getStringTel());
    TC.cleanStringTel();*/
}

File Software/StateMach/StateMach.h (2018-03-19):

#ifndef StateMach_h
#define StateMach_h

#include <Arduino.h>
#include "hDHT.h"
#include "BUZZ.h"
#include "hServo.h"
#include "hGPS.h"
#include "UVX.h"
#include "hDS18B20.h"
#include "hMS5611.h"
#include "hLSM303.h"
#include "hComm.h"
#include "telemetria_controller.h"
#include "NumericDiff.h"
#include "isFalling.h"
#include <Wire.h>
#include "TinyGPS++.h"
#include <SoftwareSerial.h>


// Pin Define
#define DHTPIN 2 // Valor a ser corrigido
#define BUZZPIN 4 // Valor a ser corrigido
#define LMSPIN

#define GPS_SS_TX 4
#define GPS_SS_RX 3

#define GPS_UBX_TX 11
#define GPS_UBX_RX 10

#define GPSBaud 9600

#define DHTTYPE DHT22

#define ExposureModeAltitude 20000.0
#define CloseWindowAltitude 25000.0
#define RescueModeAltitude 2000.0
#define MaxTimeCloseWindow 7200000

class StateMach {
private:
	// Create Objects
	int contador;
	hDHT _dht;
	BUZZ _buzzer;
	hServo _myServo;
	UVX _uvx;	
	TinyGPSPlus _gps1;
	TinyGPSPlus _gps2;
	SoftwareSerial _ss;
	SoftwareSerial _ubk;
	hComm _hcomm;
  	telemetria_controller TC;
  	NumericDiff ND;
  	isFalling IsF;
  	char SD1[50];
  	char SD2[50];
  	char SD3[50];
  	char SD4[50];
  	char SD5[50];
  	char SDaux[50];
	// Flags de modos de operacao
	bool _climbingMode = true;
	bool _exposureMode = false;
	bool _fallingMode = false;
	bool _rescueMode = false;
	

public:
	StateMach(): _dht(DHTPIN, DHTTYPE), _buzzer(BUZZPIN), 
	_myServo(),	 _gps1(), _gps2(), _ss(GPS_SS_RX, GPS_SS_TX),
	 _ubk(GPS_UBX_RX, GPS_UBX_TX), _hcomm(), TC(), ND(1.0), IsF() {};

	void ClimbingMode();
	void ExposureMode();
	void FallingMode();
	void RescueMode();
	void Main_State();
	void START_ALL();
  	void READ_ALL();
  	void SERIAL_PRINT_ALL();
  	void SAVE_ALL();
  	void TELEMETRIA();
  	void zera_tlast();
};

#endif

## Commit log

2016-10-05 Initial commit with humidity sensor.
2016-10-12 Interface Orientada a Objeto para o Buzzer... Metodos ainda nao implementados
    [BUZZ.cpp]
2016-10-12 Interface Orientada a Objeto para o Buzzer... Metodos ainda nao implementados atualizado
    [BUZZ.cpp, onboard.ino]
2016-10-17 Classes do BUZZER finalizadas e compilando.
    [BUZZ.cpp]
2016-10-28 Biblioteca para servo compilando.
2016-11-04 subida/descida/chão
    funções da g1 que identificam subida descida e queda, através de mins
    qds
2016-11-11 Estamos sempre trabalhando para lhe proporcionar uma melhor experiencia.
2016-11-18 testando i2c
2018-03-19 TinyGPS and GPS objects updated (Compiling)
    hGPS is no longer used. SoftwareSerial and TinyGPS added.
    [StateMach.cpp, StateMach.h]
2021-04-18 organizing the repo and adding files
    [Arduino.brd, Arduino.sch, Collum.SLDPRT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]

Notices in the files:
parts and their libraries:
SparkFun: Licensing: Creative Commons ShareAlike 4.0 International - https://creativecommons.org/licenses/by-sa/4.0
